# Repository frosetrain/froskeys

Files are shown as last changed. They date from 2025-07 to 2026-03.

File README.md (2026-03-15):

# Froskeys

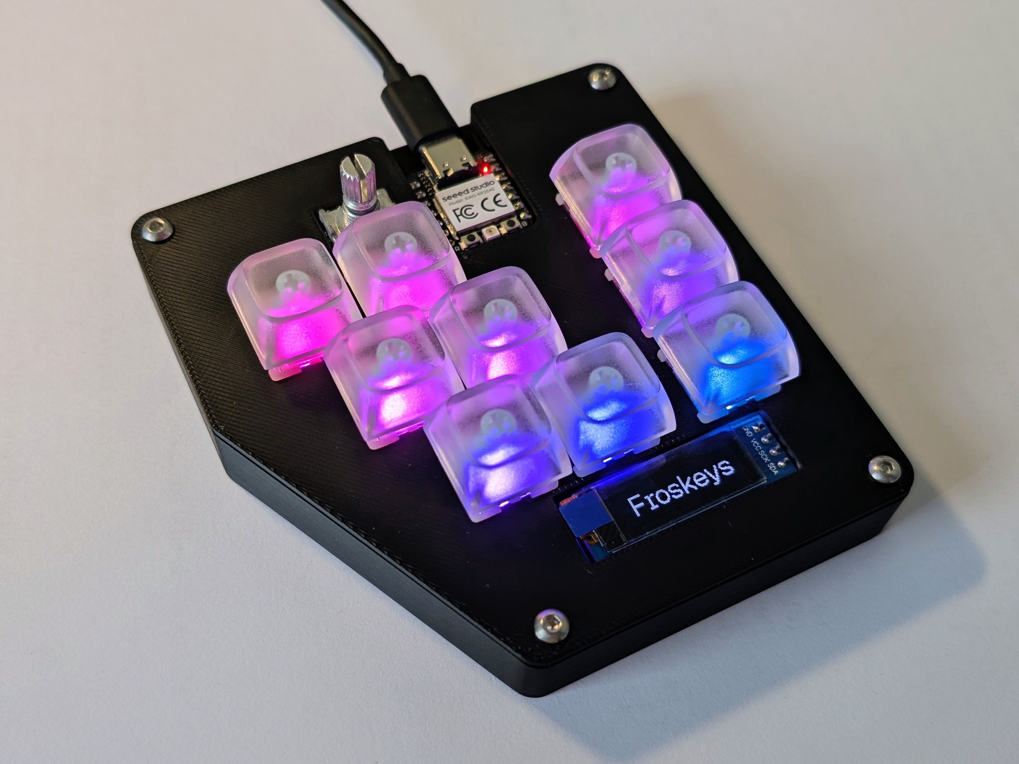
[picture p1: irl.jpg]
Photo of Froskeys macropad


[Demo video](https://www.youtube.com/watch?v=2AYCUWPBNlQ)

A 9-key macropad that I created for my own use-cases. I wanted some more keys next to my keyboard to do things like push-to-talk and other macros. Since my mouse is on the right of my laptop, my macropad shall sit on the left of my laptop.

There is a column of keys on the right of the macropad, to easily press with my pinky while my left hand is on WASD.

There is a diagonal cutout on the bottom left, where I can rest my hand more easily.

## Keys

- Control+Z (undo) and Control+Y (redo)
- Control+C (copy) and Control+V (paste), the only two keys I need
- Control+D (duplicate)
- F2 (rename)
- Play/pause
- Push-to-talk
- `fastfetch`

## Schematic

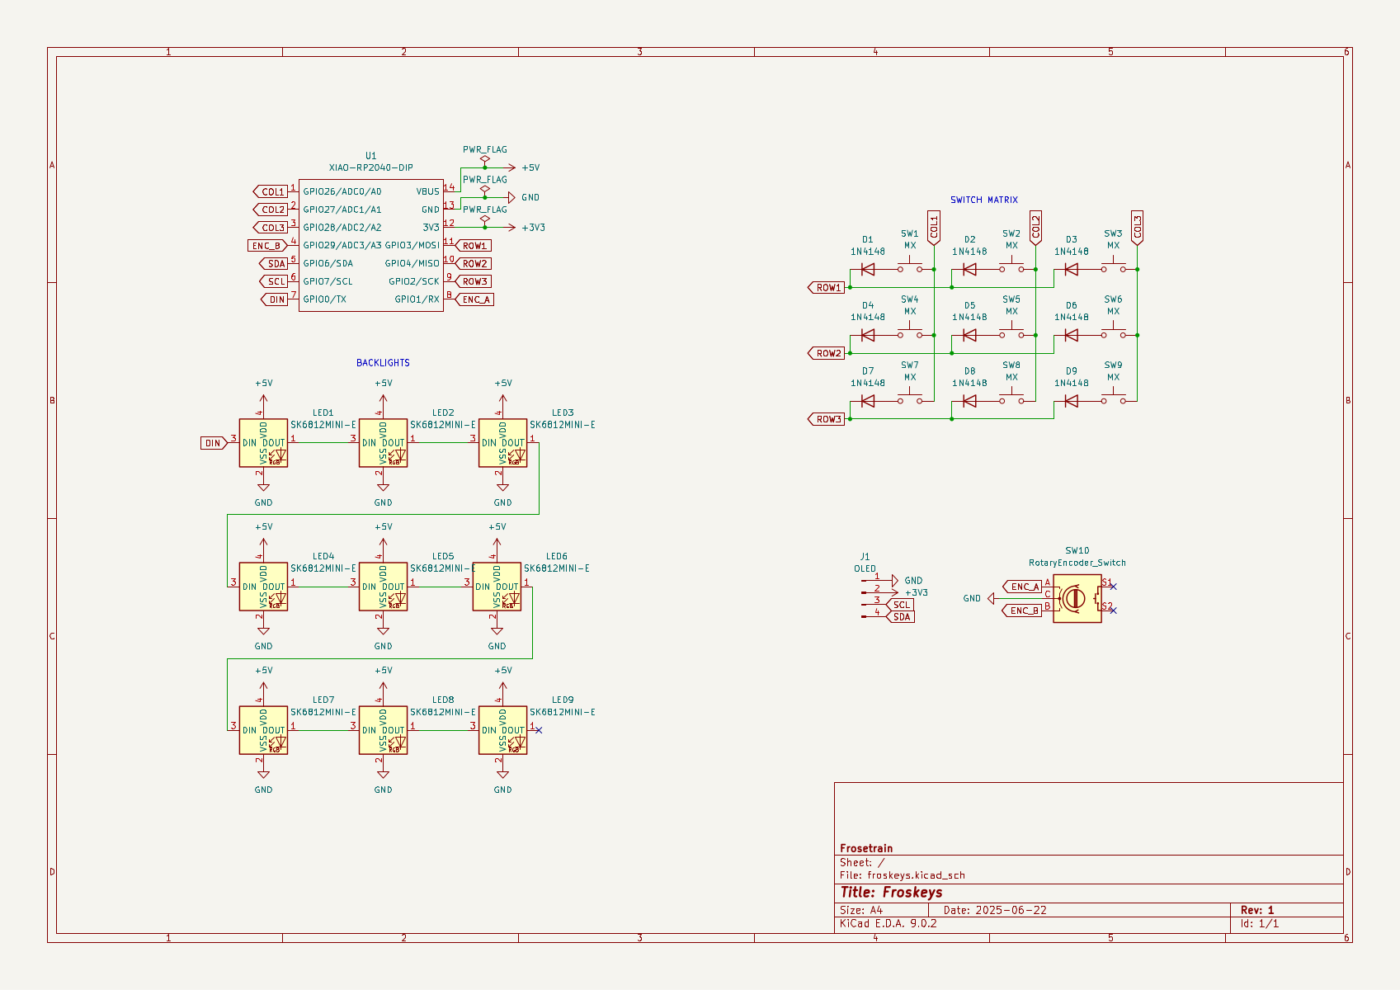
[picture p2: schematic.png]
Schematic


## PCB

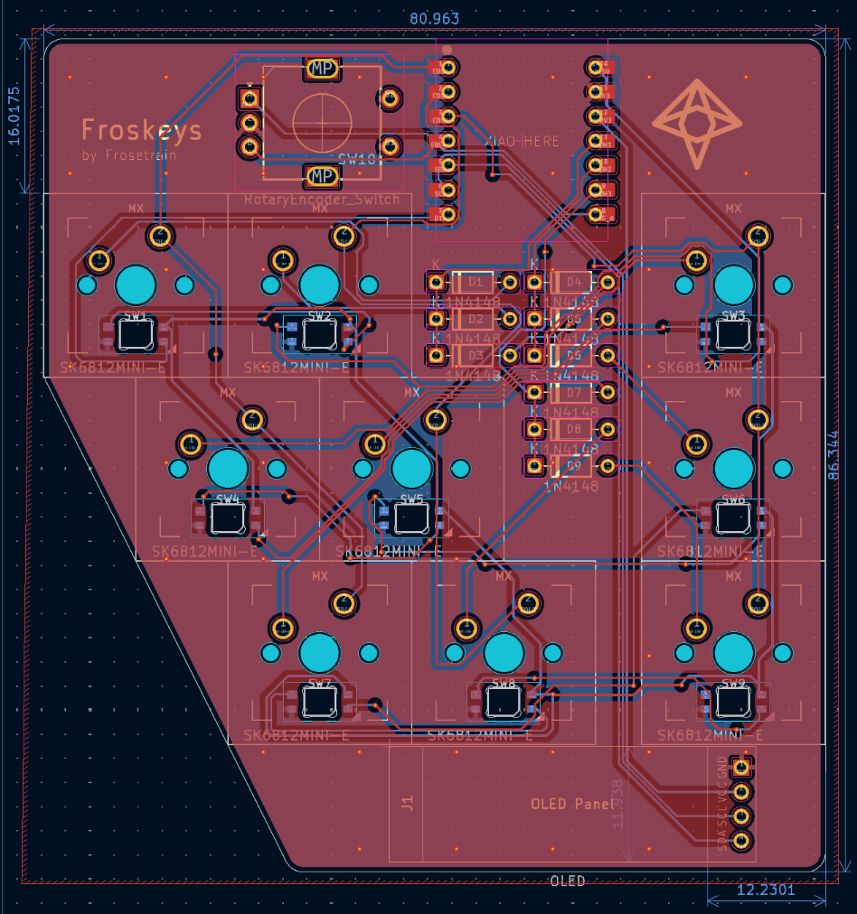
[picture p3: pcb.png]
PCB


## Case

| Top | Bottom |
| --- | --- |
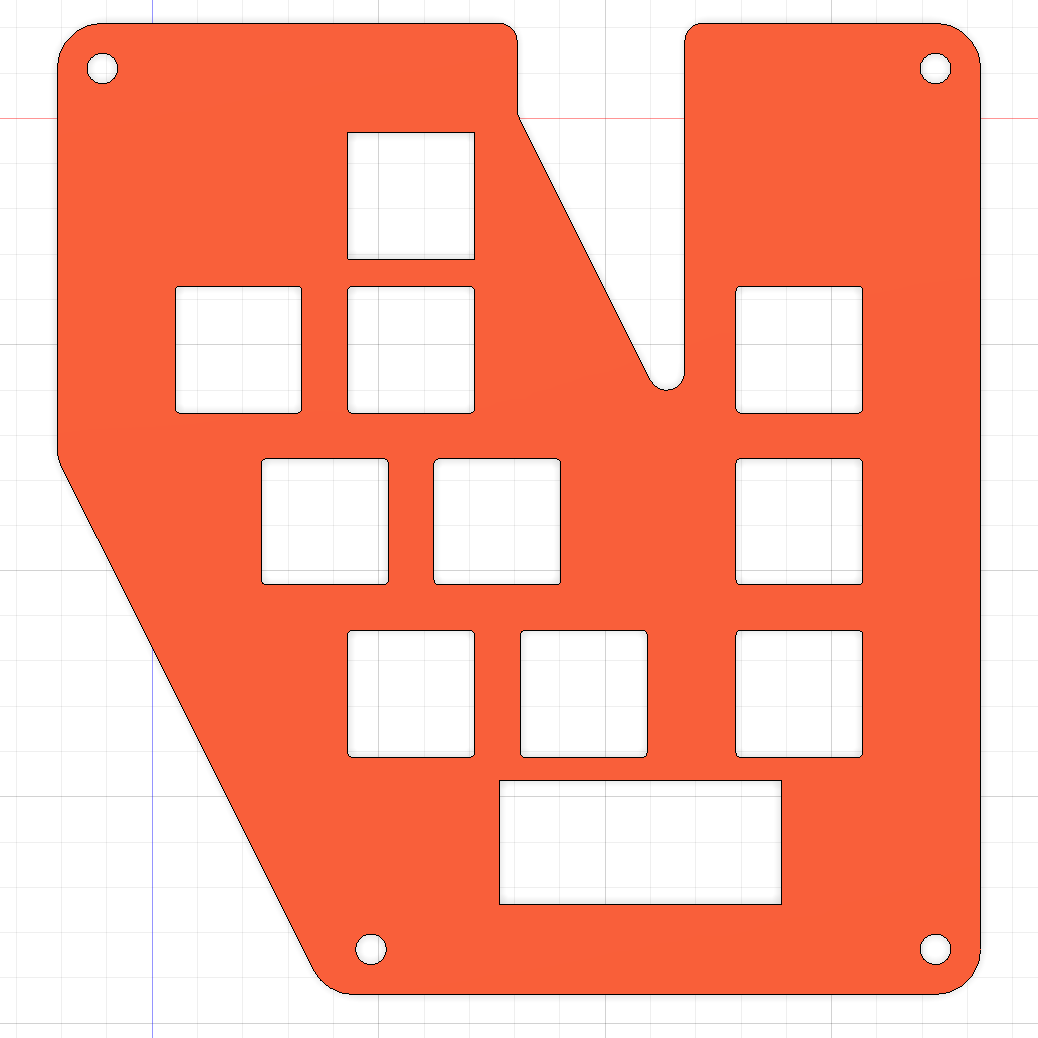
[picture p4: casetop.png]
Top of case
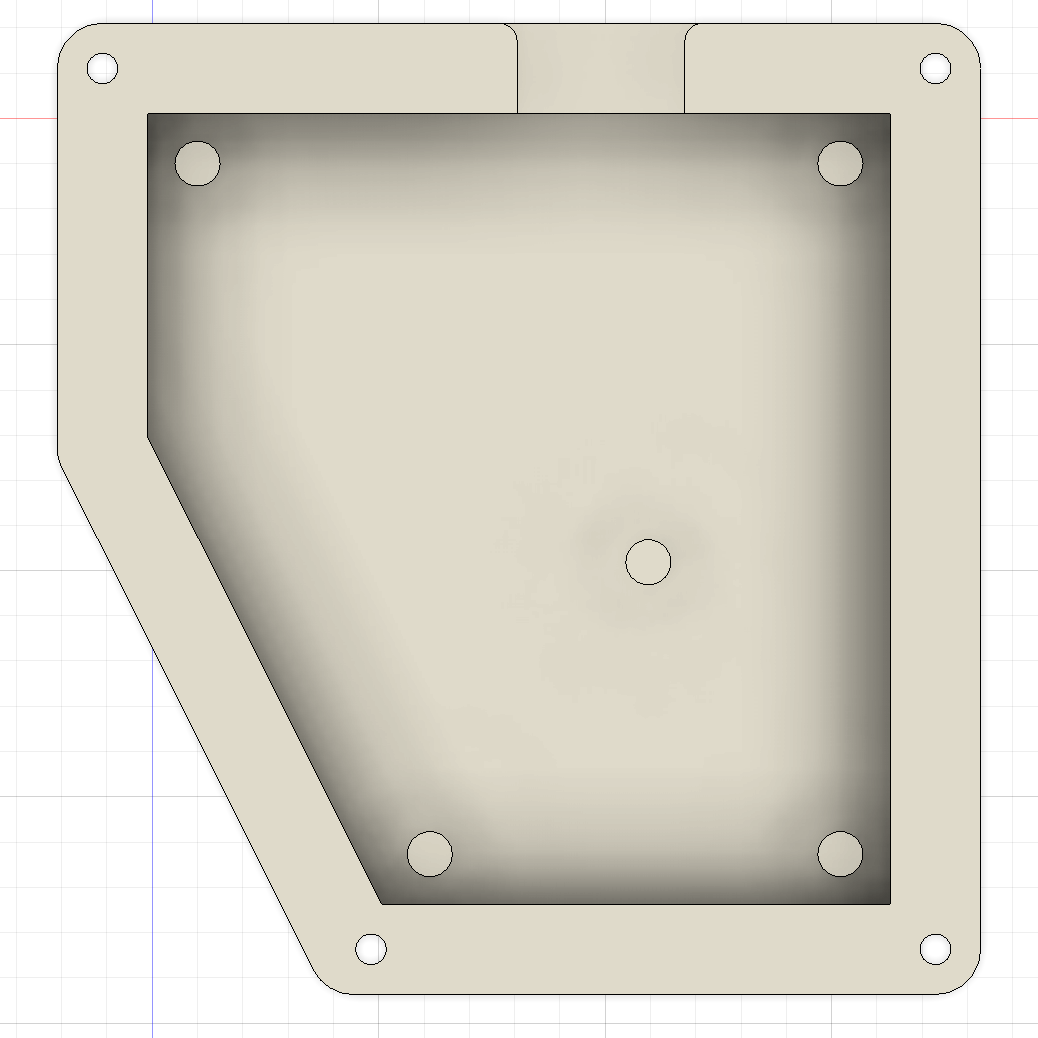
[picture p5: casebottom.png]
Bottom of case
|  |  |

**CAD render**

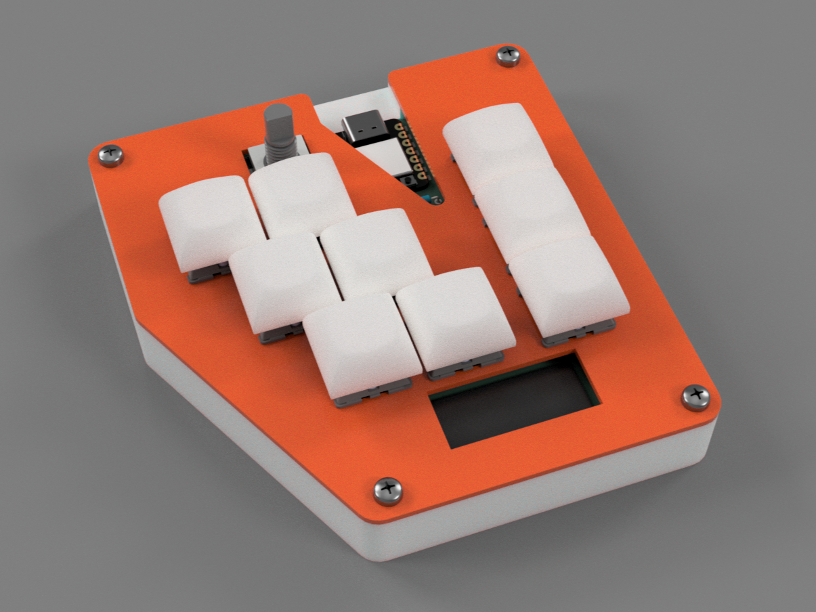
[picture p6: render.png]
Render of Froskeys macropad


Section analysis was a very useful feature

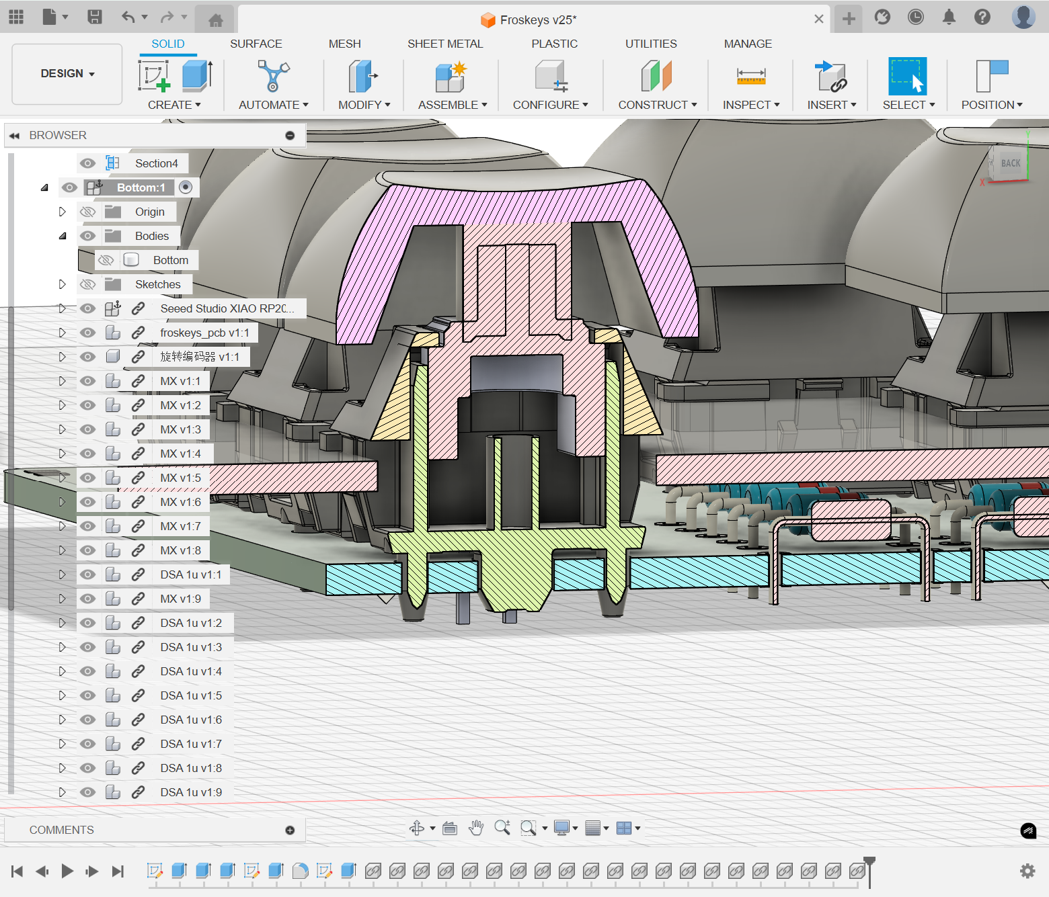
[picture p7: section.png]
Section analysis


## BOM

### JLCPCB

- PCB

### 3D Printed

- Case

### Components

- 1 × Seeed Studio XIAO RP2040
- 9 × 1N4148 Diode
- 1 × EC11 Rotary Encoder
- 1 × 0.91″ I²C OLED Display
- 9 × White XDA Profile PBT Keycaps
- 9 × SK6812 MINI-E LED
- 4 × M3×16mm screw
- 4 × M3×5mm×4mm heatset insert
- 9 × Gateron Baby Kangaroo 2.0

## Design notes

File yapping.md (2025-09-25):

## Switches

actation, bottom out, travel, price (SGD)

58 62 3.4 7.40 Gateron Baby Kangaroo 2.0 (very deep actuation)
58 62 3.5 6.90 Durock Ice King
?? 65 3.2 8.60 Gazzew U4T

## Money

$8.00 (mash)
$7.40 (pantheon)
US$6.00 (unikeyboards)

pantheon shipping $4.20 or $4.50
mash shipping $5.00
unikeyboard shipping US$3.00

mash total $13 = US$10.14
pantheon total $11.6 = US$9.05
unikeyboard total US$9

components are $10.50 = US$8.19

9 USD for components
10 USD for switches

total grant request 19 USD

## Assembly

1. PCB
2. 3D printed case
3. Inventory parts
4. Aliexpress parts
5. Switches

I have the most control over the PCB and 3D printed case, so those shall be ordered last

Should I delay the buying of switches until I get the inventory parts? Nah, the keycaps will probably fit
The Inventory and Aliexpress parts have no dependency on each other so I can buy it from Aliexpress immediately (after the grant appears)

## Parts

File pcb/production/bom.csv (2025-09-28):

Designator | Footprint | Quantity | Value | LCSC Part #
D1, D2, D3, D4, D5, D6, D7, D8, D9 | D_DO-35_SOD27_P7.62mm_Horizontal | 9 | 1N4148
J1 | SSD1306-0.91-OLED-4pin-128x32 | 1 | OLED
LED1, LED2, LED3, LED4, LED5, LED6, LED7, LED8, LED9 | MX_SK6812MINI-E_GOOD | 9 | SK6812MINI-E
SW1, SW2, SW3, SW4, SW5, SW6, SW7, SW8, SW9 | MX-Solderable-1U | 9 | MX
SW10 | RotaryEncoder_Alps_EC11E-Switch_Vertical_H20mm | 1 | RotaryEncoder_Switch
U1 | XIAO-RP2040-DIP | 1 | XIAO-RP2040-DIP

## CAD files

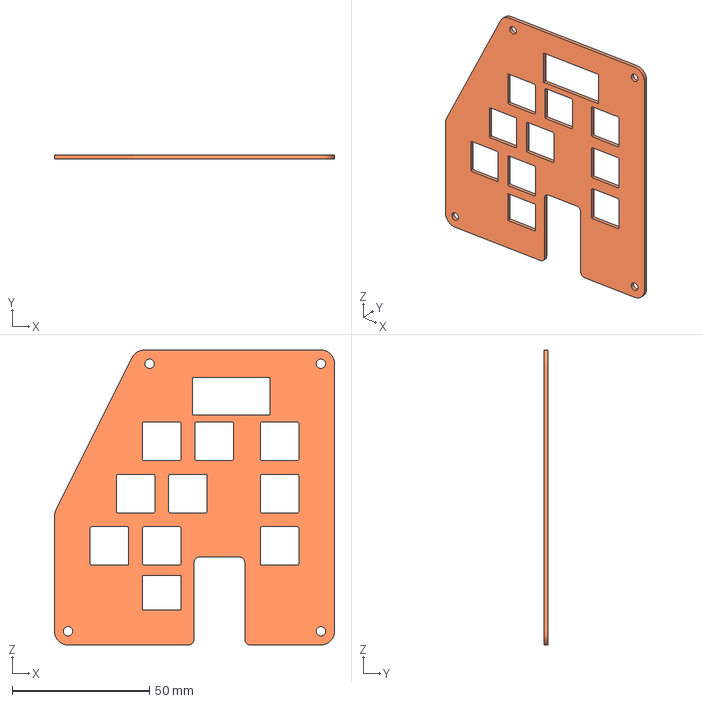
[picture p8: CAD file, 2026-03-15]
production/Top.3mf
102.0 x 1.50 x 107.3 mm

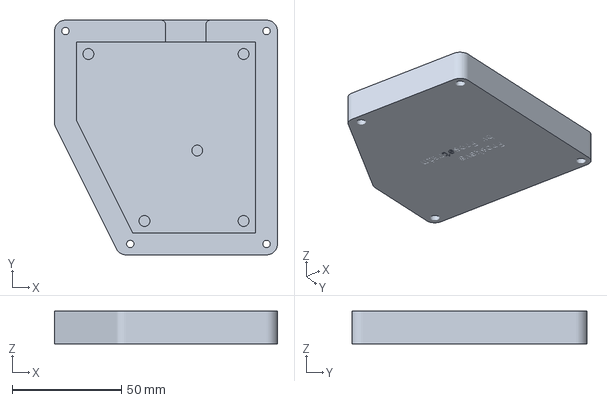
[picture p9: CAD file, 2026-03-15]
production/Bottom.3mf
102.0 x 107.3 x 15.0 mm

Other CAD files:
production/froskeys-bottom.gcode.3mf
production/froskeys.gcode.3mf
production/froskeys-top.gcode.3mf

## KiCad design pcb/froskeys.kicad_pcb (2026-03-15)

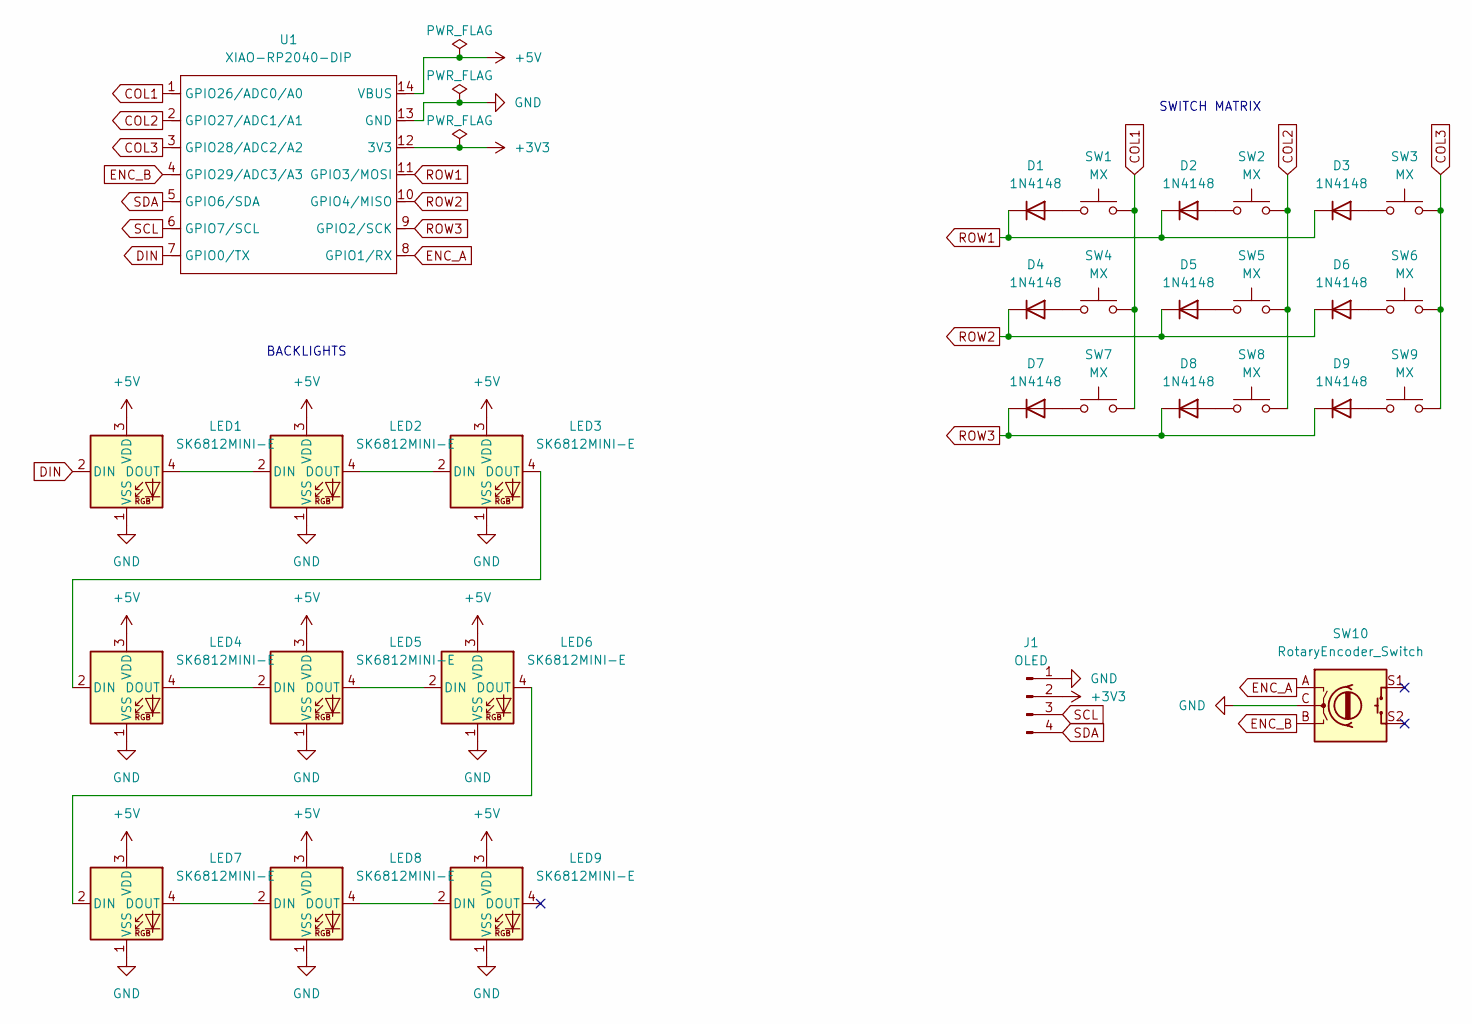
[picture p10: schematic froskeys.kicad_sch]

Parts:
D1, D2, D3, D4, D5, D6, D7, D8, D9: 1N4148; D_DO-35_SOD27_P7.62mm_Horizontal
J1: OLED; SSD1306-0.91-OLED-4pin-128x32
LED1, LED2, LED3, LED4, LED5, LED6, LED7, LED8, LED9: SK6812MINI-E; MX_SK6812MINI-E_GOOD
SW1, SW2, SW3, SW4, SW5, SW6, SW7, SW8, SW9: MX; MX-Solderable-1U
SW10: RotaryEncoder_Switch; RotaryEncoder_Alps_EC11E-Switch_Vertical_H20mm
U1: XIAO-RP2040-DIP

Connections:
+3V3: J1.2, U1.12 (3V3)
+5V: LED1.3 (VDD), LED2.3 (VDD), LED3.3 (VDD), LED4.3 (VDD), LED5.3 (VDD), LED6.3 (VDD), LED7.3 (VDD), LED8.3 (VDD), LED9.3 (VDD), U1.14 (VBUS)
COL1: SW1.2, SW4.2, SW7.2, U1.1 (GPIO26/ADC0/A0)
COL2: SW2.2, SW5.2, SW8.2, U1.2 (GPIO27/ADC1/A1)
COL3: SW3.2, SW6.2, SW9.2, U1.3 (GPIO28/ADC2/A2)
DIN: LED1.2 (DIN), U1.7 (GPIO0/TX)
ENC_A: SW10.A, U1.8 (GPIO1/RX)
ENC_B: SW10.B, U1.4 (GPIO29/ADC3/A3)
GND: J1.1, LED1.1 (VSS), LED2.1 (VSS), LED3.1 (VSS), LED4.1 (VSS), LED5.1 (VSS), LED6.1 (VSS), LED7.1 (VSS), LED8.1 (VSS), LED9.1 (VSS), SW10.C, U1.13 (GND)
unnamed: D1.2 (A), SW1.1
unnamed: D2.2 (A), SW2.1
unnamed: D3.2 (A), SW3.1
unnamed: D4.2 (A), SW4.1
unnamed: D5.2 (A), SW5.1
unnamed: D6.2 (A), SW6.1
unnamed: D7.2 (A), SW7.1
unnamed: D8.2 (A), SW8.1
unnamed: D9.2 (A), SW9.1
unnamed: LED1.4 (DOUT), LED2.2 (DIN)
unnamed: LED2.4 (DOUT), LED3.2 (DIN)
unnamed: LED3.4 (DOUT), LED4.2 (DIN)
unnamed: LED4.4 (DOUT), LED5.2 (DIN)
unnamed: LED5.4 (DOUT), LED6.2 (DIN)
unnamed: LED6.4 (DOUT), LED7.2 (DIN)
unnamed: LED7.4 (DOUT), LED8.2 (DIN)
unnamed: LED8.4 (DOUT), LED9.2 (DIN)
ROW1: D1.1 (K), D2.1 (K), D3.1 (K), U1.11 (GPIO3/MOSI)
ROW2: D4.1 (K), D5.1 (K), D6.1 (K), U1.10 (GPIO4/MISO)
ROW3: D7.1 (K), D8.1 (K), D9.1 (K), U1.9 (GPIO2/SCK)
SCL: J1.3, U1.6 (GPIO7/SCL)
SDA: J1.4, U1.5 (GPIO6/SDA)

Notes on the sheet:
SWITCH MATRIX
BACKLIGHTS

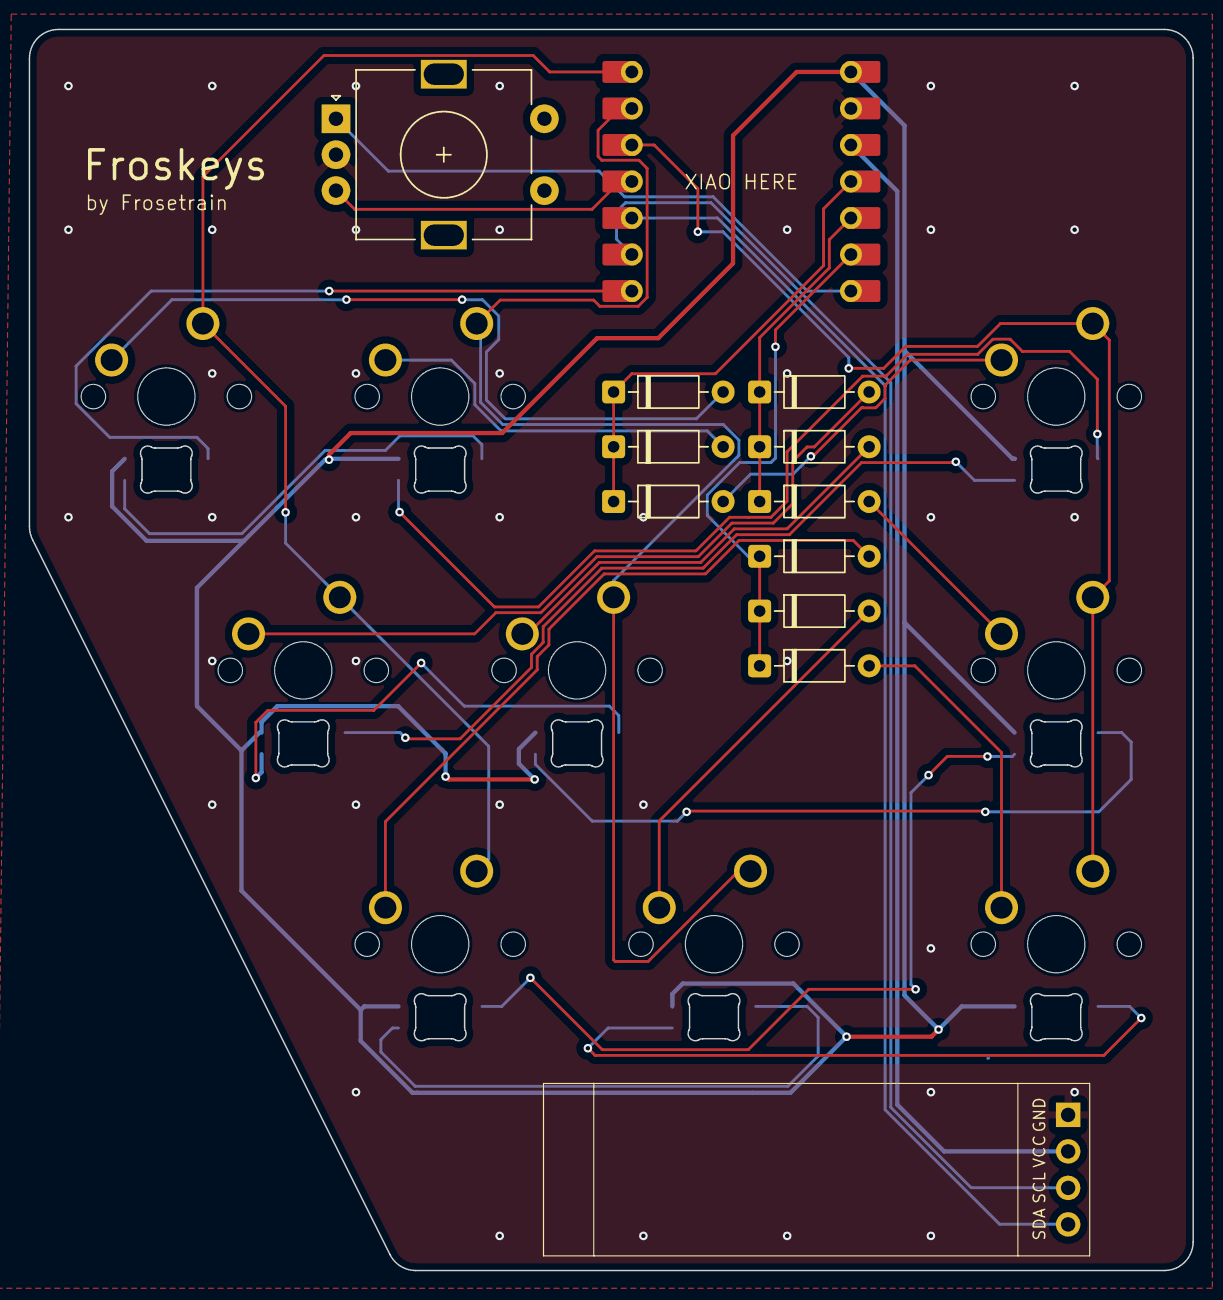
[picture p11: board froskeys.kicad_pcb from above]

Board: 2 copper layers, 81.0 x 86.3 mm, 32 parts (1 on the bottom side), 31 nets.

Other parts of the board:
KICAD: KiCad-Logo2_6mm_Copper
OSHW: OSHW-Logo_7.5x8mm_Copper

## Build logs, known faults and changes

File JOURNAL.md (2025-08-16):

---
Title: "Froskeys"
Author: "frosetrain"
Description: "A 9-key macropad that I created for my own use-cases"
Created On: "2025-08-16"
---

## 16 August: Converted Hackpad to Grounded project

I have a project that I created for Hackpad earlier, but I never submitted it. Alas, Hackpad had ended when I tried submitting it, so it is time to do Grounded instead! It seems some the parts for my hackpad are provided by the hardware grant inventory. Very cool. Please forgive me for the fact that my journal only has one entry, since all of the work was done before Grounded started.

My main problem now is to figure out how to get my parts, with some from the inventory and some from other suppliers using the grant. Looking at my BOM, 6 types of parts are available in the inventory, while 3 are not. I decided to use AliExpress to buy the heatset inserts that Hackpad linked to. I also found screws and addressable LEDs, also on AliExpress, so I added those to the same cart.

I might just get some nicer switches using the budget, because clicky is 🤮. Since it’s a macropad, it isn’t really typing, but individually pressing keys. I think I should get tactile instead of linear, so I know when it actuates. I ended up looking at some tactile switches online and checking each switch’s actuation force and bottom-out force. I also only looked at switches with a transparent casing because I have RGB on my macropad. Eventually I decided on the Gateron Baby Kangaroo 2.0.

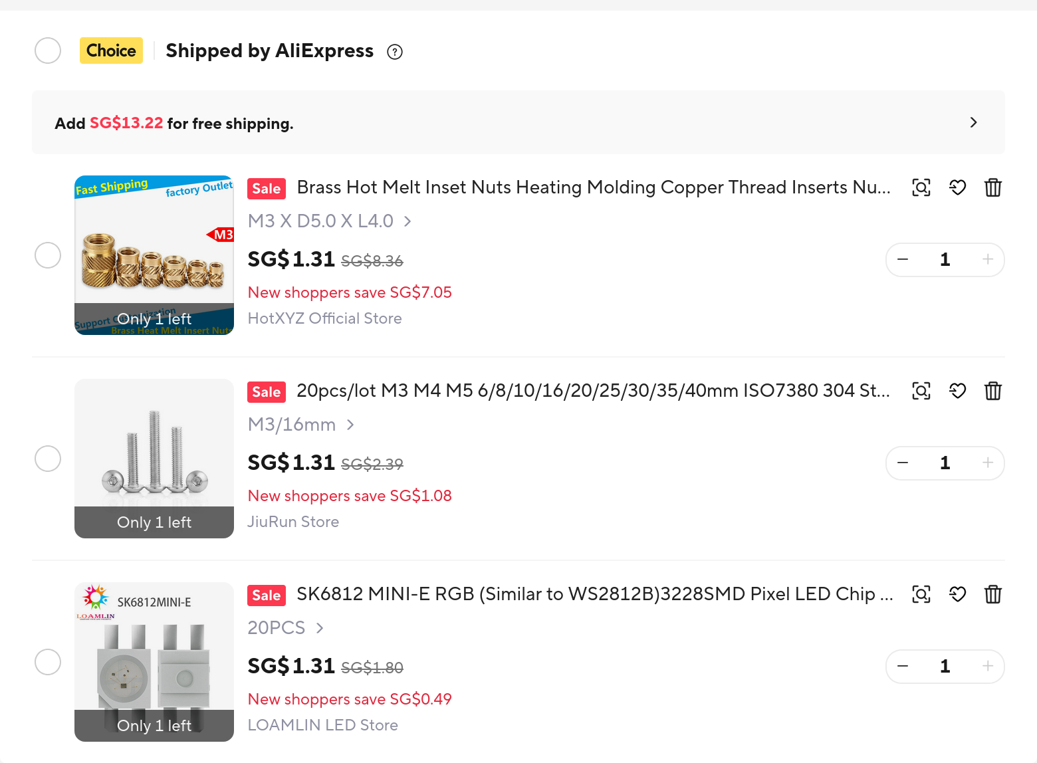
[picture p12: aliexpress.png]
AliExpress cart


**Total time spent: 3h**

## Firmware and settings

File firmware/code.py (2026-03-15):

"""KMK firmware for Froskeys."""

import board
import busio as io
from kmk.extensions.display import Display, ImageEntry
from kmk.extensions.display.ssd1306 import SSD1306
from kmk.extensions.media_keys import MediaKeys
from kmk.extensions.RGB import RGB, AnimationModes
from kmk.keys import KC, make_key
from kmk.kmk_keyboard import KMKKeyboard
from kmk.modules.combos import Chord, Combos
from kmk.modules.encoder import EncoderHandler
from kmk.modules.layers import Layers
from kmk.modules.macros import Delay, Macros, Press, Release, Tap
from kmk.scanners import DiodeOrientation

# What is this for
make_key(
    names=("MYKEY",),
    on_press=lambda *args: print("I pressed MYKEY"),
)

# Initialise keyboard hardware, modules and extensions
keyboard = KMKKeyboard()
combos = Combos([Chord((0, 1), KC.MYKEY, match_coord=True)])
encoder = EncoderHandler()
rgb = RGB(
    pixel_pin=board.D6, num_pixels=9, val_limit=128, animation_mode=AnimationModes.SWIRL
)

oled_i2c = io.I2C(sda=board.D4, scl=board.D5, frequency=400_000)
oled_display = Display(
    display=SSD1306(oled_i2c),
    width=128,
    height=32,
    flip=True,
    entries=[ImageEntry(0, 0, "froskeys-oled.bmp")],
)

# Load modules and extensions
keyboard.modules = [Macros()]
keyboard.extensions = [
    MediaKeys(),
    Macros(),
    Layers(),
    combos,
    encoder,
    oled_display,
    rgb,
]

# Set encoder parameters
encoder.pins = ((board.D3, board.D7, None),)
encoder.map = [
    ((KC.AUDIO_VOL_DOWN, KC.AUDIO_VOL_UP, KC.NO),),
    ((KC.BRIGHTNESS_DOWN, KC.BRIGHTNESS_UP, KC.NO),),
]

# Funny macro
PACMAN_SYU = KC.MACRO(
    Press(KC.LGUI),
    Tap(KC.T),
    Release(KC.LGUI),
    Delay(500),
    "fastfetch",
    Tap(KC.ENTER),
)

# Set keyboard parameters
keyboard.col_pins = (board.D0, board.D1, board.D2)
keyboard.row_pins = (board.D10, board.D9, board.D8)
keyboard.diode_orientation = DiodeOrientation.COL2ROW
keyboard.keymap = [
    # [
    #     KC.LCTL(KC.Z),
    #     KC.LCTL(KC.Y),
    #     KC.MEDIA_PLAY_PAUSE,
    #     KC.F2,
    #     KC.LCTL(KC.D),
    #     PACMAN_SYU,
    #     KC.LCTL(KC.C),
    #     KC.LCTL(KC.V),
    #     KC.KP_EQUAL_AS400,
    # ],
    [
        KC.E,
        KC.W,
        KC.R,
        KC.A,
        KC.S,
        KC.D,
        KC.C,
        KC.LSHIFT,
        KC.SPACE,
    ],
    [KC.TRNS] * 9,  # Transparent
]

if __name__ == "__main__":
    keyboard.go()

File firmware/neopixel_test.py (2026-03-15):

import board
import neopixel
import time
from rainbowio import colorwheel

NUM_PIXELS = 9

pixels = neopixel.NeoPixel(board.D6, NUM_PIXELS, brightness=0.1)


def rainbow_cycle(wait):
    for j in range(255):
        for i in range(NUM_PIXELS):
            rc_index = (i * 64 // NUM_PIXELS) + j
            pixels[i] = colorwheel(rc_index & 255)
        pixels.show()
        time.sleep(wait)


while True:
    rainbow_cycle(0)
    # pixels.fill((100, 0, 0))
    # pixels.show()
    # time.sleep(0.2)
    # pixels.fill((0, 100, 0))
    # pixels.show()
    # time.sleep(0.2)
    # pixels.fill((0, 0, 100))
    # pixels.show()
    # time.sleep(0.2)

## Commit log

2025-06-23 Seems cool
    [froskeys.kicad_pcb]
2025-06-23 Is this good
    [froskeys.kicad_pcb]
2025-06-26 Switch to SK6812MINI-E backlighting
    [froskeys.kicad_pcb, froskeys.kicad_sch]
2025-07-07 Add gerbers
    [Bottom.stl, Top.stl, bom.csv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]
2025-08-16 Convert to Grounded project
2025-09-25 Hmm this is interesting
    [Top.stl]
2025-09-26 Mm fix encoder
2025-09-26 Switch to SEEED pin numbers
2025-09-26 Change encoder direction and add SK6812 test
2025-09-28 Change SK6812 pin order
    [bom.csv, designators.csv, froskeys.kicad_pcb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]
2025-09-28 Oops add stitching vias
    [froskeys.kicad_pcb]
